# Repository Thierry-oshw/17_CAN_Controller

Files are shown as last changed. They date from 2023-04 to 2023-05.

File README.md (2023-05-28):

# Can controller and CAN transceiver module

Can module to easily add CAN support to anything with SPI

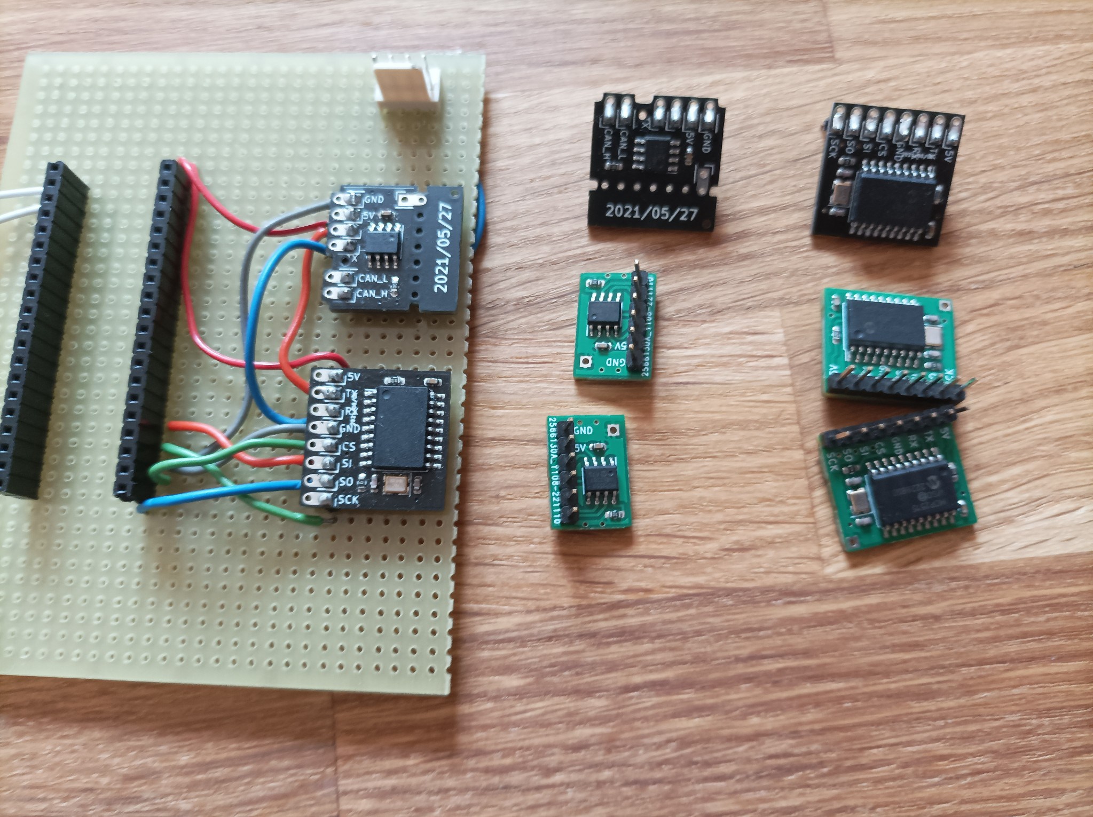
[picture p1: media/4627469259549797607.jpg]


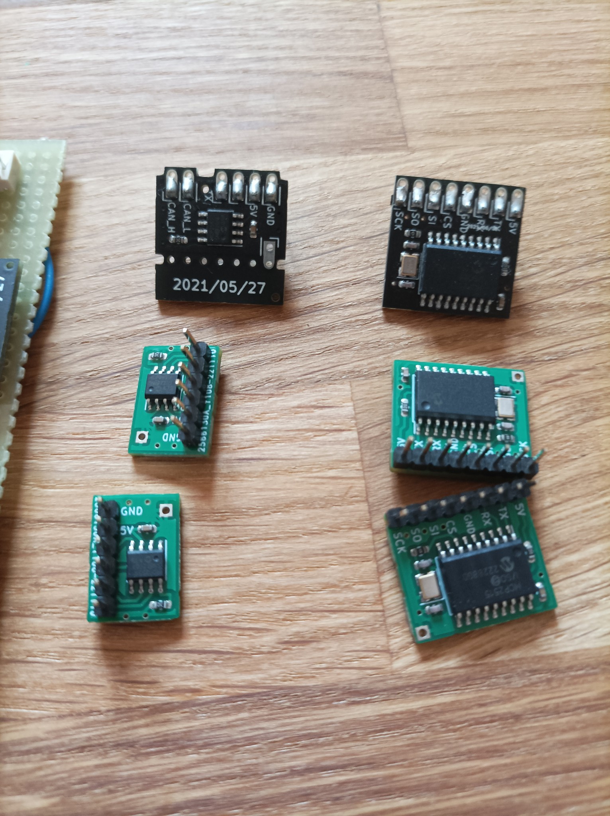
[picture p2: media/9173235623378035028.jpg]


[Link for controller](https://github.com/Thierry-oshw/17_CAN_Controller)

[Link for transceiver](https://github.com/Thierry-oshw/15_XCAN)

## Features
- Small (Controller is 18x20 mm, Transceiver is 17x15 mm)
- Cheap (2 layer and components on one side)
- 2.54 header + castellated pad for direct board to board soldering

## Made with

- [Kicad V6](https://www.kicad.org/)

## Schematic

### 15 XCAN Schematic

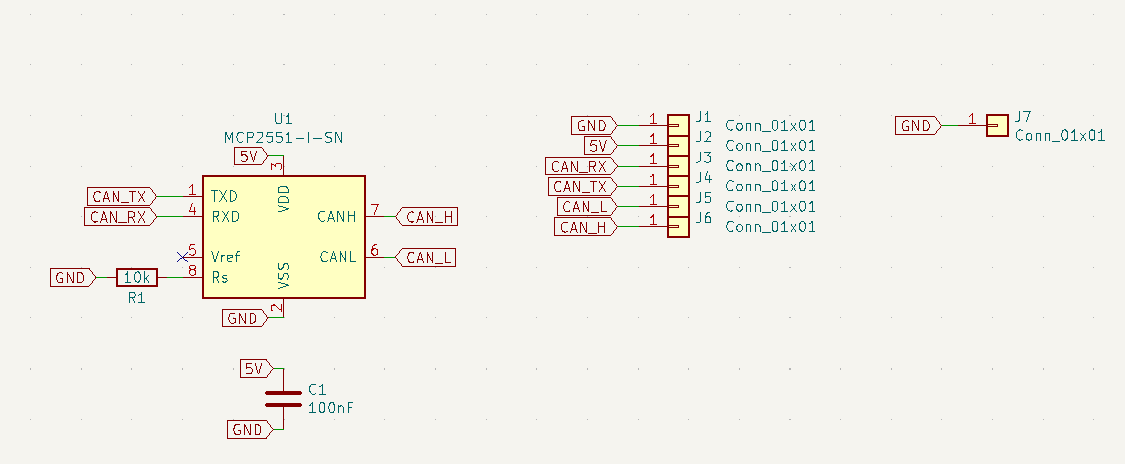
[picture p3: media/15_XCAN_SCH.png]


### 17 CAN Controller Schematic

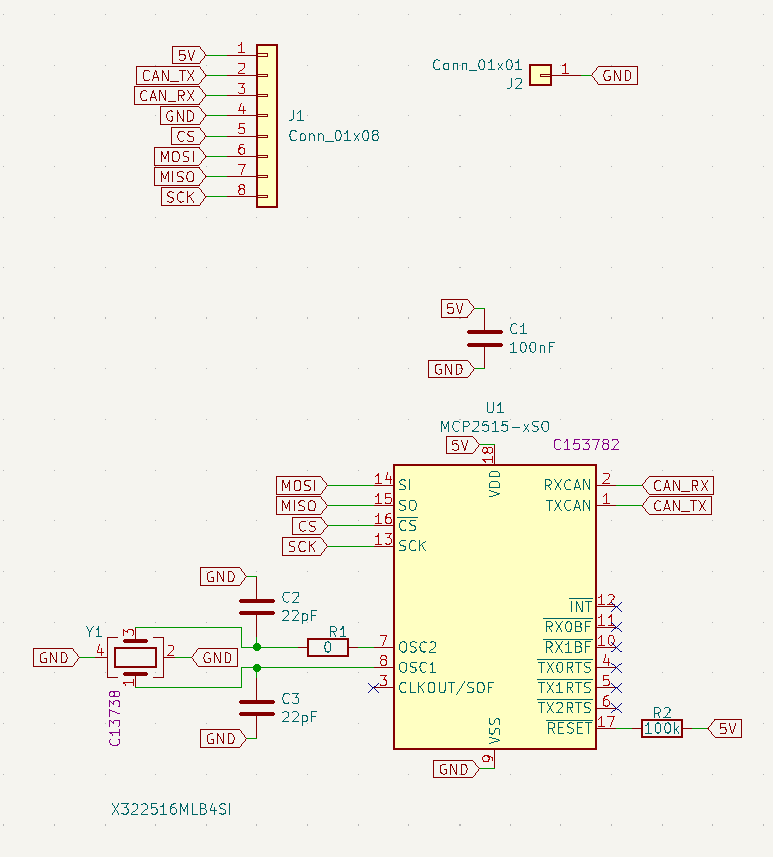
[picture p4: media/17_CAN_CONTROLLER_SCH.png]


## Build the PCB

PCB has been fully tested on multiple projects

[CAN Controller build files](https://github.com/Thierry-oshw/17_CAN_Controller/tree/main/fabrication_2023_04_23)

[CAN Transceiver build files without castellated holes](https://github.com/Thierry-oshw/15_XCAN/tree/main/fabrication_2023_04_21)

[CAN Transceiver build files with castellated holes](https://github.com/Thierry-oshw/15_XCAN/tree/main/fabrication_2023_04_21_CH)

## Authors

- Thierry Orlandi ([Hardware Freelance](https://www.linkedin.com/in/thierry-orlandi))
- Yohann Belair ([R&D Freelance](https://github.com/ciborg971))

## License
[CERN Open Hardware Licence Version 2](https://github.com/Thierry-oshw/17_CAN_Controller/blob/main/LICENSE.txt)

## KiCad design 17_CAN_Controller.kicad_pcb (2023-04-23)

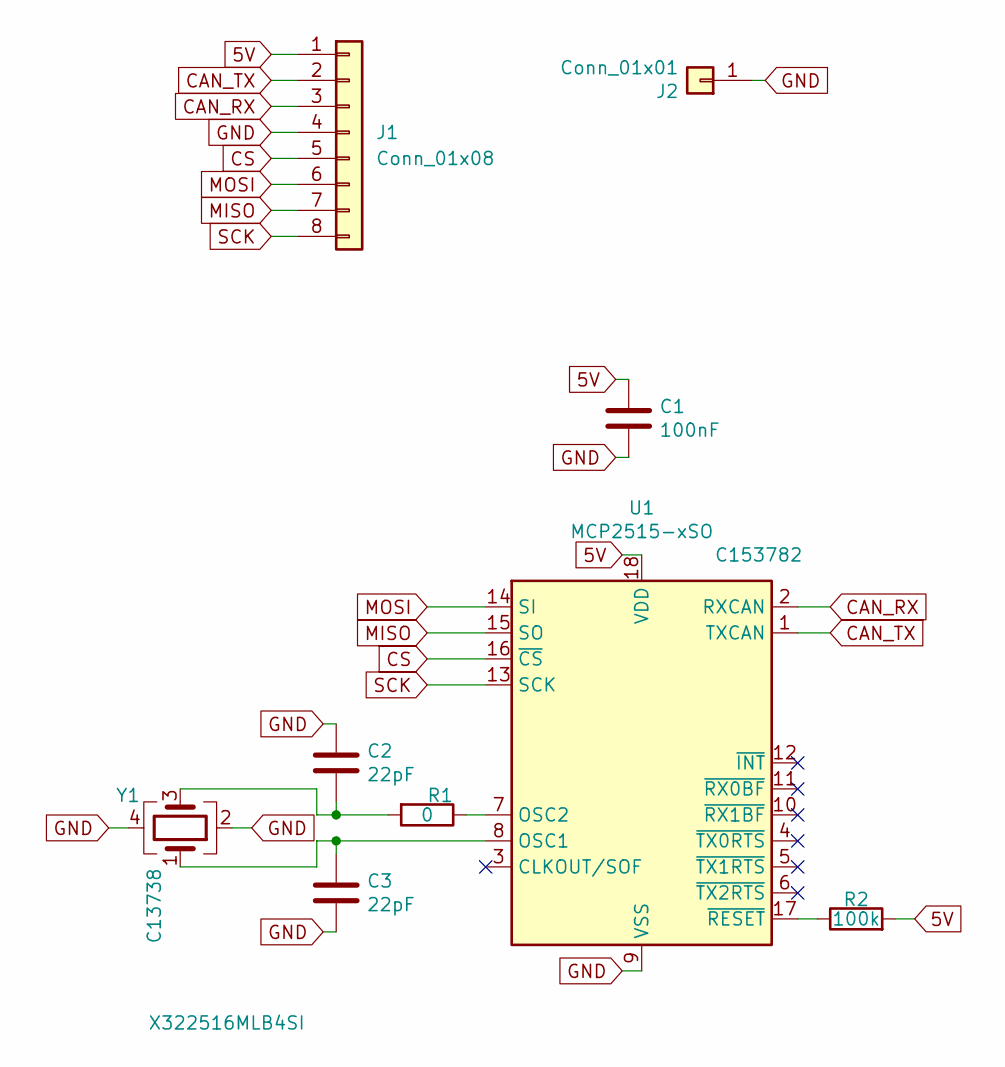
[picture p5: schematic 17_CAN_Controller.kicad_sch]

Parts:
C1: 100nF; C_0603_1608Metric; LCSC C14663
C2, C3: 22pF; C_0603_1608Metric; LCSC C1653
J1: Conn_01x08; PinHeader_1x08_P2.54mm_Vertical
J2: Conn_01x01; PinHeader_1x01_P2.54mm_Vertical
R1: 0; R_0603_1608Metric; LCSC C21189
R2: 100k; R_0603_1608Metric; LCSC C25803
U1: MCP2515-xSO; SOIC-18W_7.5x11.6mm_P1.27mm; LCSC C153782
Y1: X322516MLB4SI; Crystal_SMD_3225-4Pin_3.2x2.5mm; LCSC C13738

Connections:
5V: C1.1, J1.1, R2.2, U1.18 (VDD)
CAN_RX: J1.3, U1.2 (RXCAN)
CAN_TX: J1.2, U1.1 (TXCAN)
CS: J1.5, U1.16 (~CS)
GND: C1.2, C2.1, C3.2, J1.4, J2.1, U1.9 (VSS), Y1.2, Y1.4
MISO: J1.7, U1.15 (SO)
MOSI: J1.6, U1.14 (SI)
unnamed: C3.1, U1.8 (OSC1), Y1.1
unnamed: R1.1, U1.7 (OSC2)
unnamed: C2.2, R1.2, Y1.3
unnamed: R2.1, U1.17 (~RESET)
SCK: J1.8, U1.13 (SCK)

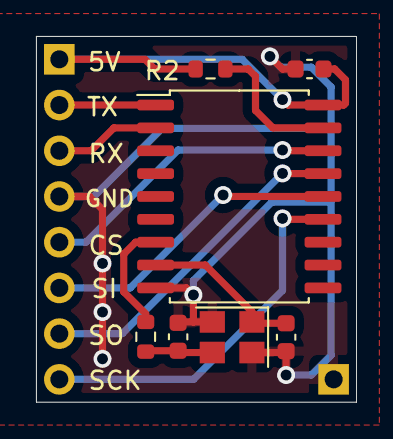
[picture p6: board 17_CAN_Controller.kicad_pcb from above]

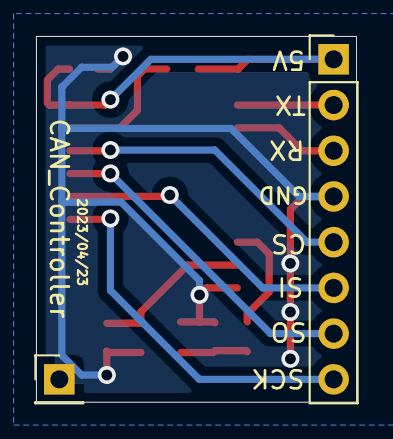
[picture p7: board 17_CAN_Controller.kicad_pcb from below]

Board: 2 copper layers, 17.8 x 20.3 mm, 9 parts (2 on the bottom side), 12 nets.

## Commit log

2021-06-01 schema + routage
    [17_CAN_Controller-B_Cu.gbr, 17_CAN_Controller-B_Fab.gbr, 17_CAN_Controller-B_Mask.gbr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]
2021-07-26 maj split librairies
    [17_CAN_Controller.kicad_pcb, 17_CAN_Controller.sch]
2022-10-31 maj kicad 6
    + correction chemin
    + step
    [17_CAN_Controller.kicad_pcb, 17_CAN_Controller.kicad_sch, 17_CAN_Controller.step]
2022-11-03 maj réduction de taille
    [17_CAN_Controller.kicad_pcb, 17_CAN_Controller.kicad_sch, 17_CAN_Controller.step]
2022-11-03 connecteur passe de wrl à step
    [17_CAN_Controller.kicad_pcb]
2022-11-06 gerbers maj kicad 6 jlcpcb
    [17_CAN_Controller-B_Cu.gbl, 17_CAN_Controller-B_Cu.gbr, 17_CAN_Controller-B_Fab.gbr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]
2022-11-06 maj kicad 6 jlcpcb
    [17_CAN_Controller.kicad_sch, 17_CAN_Controller.sch]
2022-11-07 zip pour voir position et bom
2023-04-23 maj librairies et silk
    [17_CAN_Controller-B_Cu.gbl, 17_CAN_Controller-B_Fab.gbr, 17_CAN_Controller-B_Mask.gbs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]
